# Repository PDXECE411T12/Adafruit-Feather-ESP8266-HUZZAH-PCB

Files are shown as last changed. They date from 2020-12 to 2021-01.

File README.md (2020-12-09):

# Modified for:
## ECE 411 Team 12 
### RFID Smart Lock

#### Fall 2020
#### Authors: Miles Breslin, Miguel Higgins Moy, John Sharpe, Noah Page

## Adafruit Feather HUZZAH with ESP8266 - Loose Headers PCB

<a href="http://www.adafruit.com/products/2821"><br/>
Click here to purchase one from the Adafruit shop</a>

PCB files for the Adafruit Feather HUZZAH with ESP8266 - Loose Headers. Format is EagleCAD schematic and board layout
* https://www.adafruit.com/product/2821

### Description

Feather is the new development board from Adafruit, and like its namesake it is thin, light, and lets you fly! We designed Feather to be a new standard for portable microcontroller cores.

This is the **Adafruit Feather HUZZAH ESP8266** - our take on an 'all-in-one' ESP8266 WiFi development board with built in USB and battery charging. Its an ESP8266 WiFi module with all the extras you need, ready to rock! [We have other boards in the Feather family, check'em out here.](https://www.adafruit.com/feather)

At the Feather HUZZAH's heart is an ESP8266 WiFi microcontroller clocked at 80 MHz and at 3.3V logic. This microcontroller contains a Tensilica chip core as well as a full WiFi stack. You can program the microcontroller using the Arduino IDE for an easy-to-run Internet of Things core. We wired up a high-quality SiLabs CP2104 USB-Serial chip that can upload code at a blistering 921600 baud for fast development time. It also has auto-reset so no noodling with pins and reset button pressings. The CP2104 has better driver support than the CH340 and can do very high speeds without stability issues.

To make it easy to use for portable projects, we added a connector for any of our 3.7V Lithium polymer batteries and built in battery charging. You don't need a battery, it will run just fine straight from the micro USB connector. But, if you do have a battery, you can take it on the go, then plug in the USB to recharge. The Feather will automatically switch over to USB power when its available.

**Here's some handy specs!**

 * Measures 2.0" x 0.9" x 0.28" (51mm x 23mm x 8mm) without headers soldered in
 * Light as a (large?) feather - 9.7 grams
 * ESP8266 @ 80MHz with 3.3V logic/power
 * 4MB of FLASH (32 MBit)
 * Built in WiFi 802.11 b/g/n
 * 3.3V regulator with 500mA peak current output
 * CP2104 USB-Serial converter onboard with 921600 max baudrate for speedy uploading
 * Auto-reset support for getting into bootload mode before firmware upload
 * 9 x GPIO pins - can also be used as I2C and SPI
 * 1 x analog inputs 1.0V max
 * Built in 100mA LiPoly charger with charging status indicator LED, can also cut a trace to disable the charger
 * Pin #0 red LED for general purpose blinking. Pin #2 blue LED for bootloading debug & general purpose blinking
 * Power/enable pin
 * 4 mounting holes
 * Reset button
Comes fully assembled and tested, with a USB interface that lets you quickly use it with the Arduino IDE or NodeMCU Lua (it comes preprogrammed with the Lua interpreter). We also toss in some headers so you can solder it in and plug into a solderless breadboard. **Lipoly battery and USB cable not included** (but we do have lots of options in the shop if you'd like!)

[Check out our tutorial for all sorts of details, including schematics, files, IDE instructions, power management and more!](https://learn.adafruit.com/adafruit-feather-huzzah-esp8266)

### License

Adafruit invests time and resources providing this open source design, please support Adafruit and open-source hardware by purchasing products from [Adafruit](https://www.adafruit.com)!

Designed by Limor Fried/Ladyada for Adafruit Industries.

Creative Commons Attribution/Share-Alike, all text above must be included in any redistribution. See license.txt for additional details.

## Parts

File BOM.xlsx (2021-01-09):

Bill Of Materials for: Team 12 RFID Door Lock
Last modified: 1/8/21
PCB version: F
BOM revision: 5 |  | P/NP | Place/Not Place (components marked NP are not stuffed on the board)
 |  |  |  |  |  |  |  |  |  |  |  |  | Combined Info for Bag Labels
Cnt | Part References | P/NP | Mfg | Value | Package | Mfg PN | Description | Dist | Dist Part Number | Link | Cost Ea. | Cost Total
1 | - | NP | OshPark | - | - | - | OshPark PCB | OshPark | - | - | $6.92 | $6.92 | QTY | REF | VALUE | PART#
1 | X1 | P | Espressif Systems | - | - | ESP-12E | Microcontroller | Digikey | 1528-1438-ND | https://www.digikey.com/en/products/detail/adafruit-industries-llc/2491/5761206 | $6.95 | $6.95
1 | M1 | NP | Tower Pro | - | - | MG90S | Micro servo | Smart Prototyping |  | https://www.smart-prototyping.com/MG90S-9g-metal-gear-digital-servo.html | $4.99 | $4.99 | 1 | X1 | - | 1528-1438-ND
1 | J1 | NP | NXP | - | - | MFRC522 | RFID Sensor | Amazon |  | https://www.amazon.com/MFRC-522-Reader-Inductive-Module-13-56MHz/dp/B07TYSF18Q | $1.99 | $1.99 | 1 | M1 | -
1 | X4 | P | Molex | 1050170001 | MOLEX_1050170001 | 1050170001 | USB Micro port | Digikey | WM1399CT-ND‎ | https://www.digikey.com/en/products/detail/molex,-llc/1050170001/2350885 | $0.69 | $0.69 | 1 | J1 | -
1 | U1G$1 | P | Silicon Labs | CP2104 | QFN24_4MM_SMSC | CP2104-F03-GM | USB to UART Bridge Controller | Digikey | 336-4146-1-ND | https://www.digikey.com/en/products/detail/silicon-labs/CP2104-F03-GMR/4069045 | $1.65 | $1.65 | 1 | X4 | 1050170001 | WM1399CT-ND‎
1 | Q3 | P | Alpha & Omega Semiconductor Inc. | AO3403 | SOT23-R | AO3403 | SOT-23 P-Channel MOSFET | Digikey | 785-1003-1-ND | https://www.digikey.com/en/products/detail/alpha-omega-semiconductor-inc/AO3403/1855775 | $0.28 | $0.28 | 1 | U1G$1 | CP2104 | 336-4146-1-ND
1 | AP2112-3.3 | P | MicroChip Technology | AP2112-3.3 | SOT25 | AP2112K-3.3TRG1 | Voltage Regulator | Digikey | AP2112K-3.3TRG1DICT-ND | https://www.digikey.com/en/products/detail/diodes-incorporated/AP2112K-3-3TRG1/4470746 | $0.36 | $0.36 | 1 | Q3 | AO3403 | 785-1003-1-ND
2 | JP2, JP3 | NP | Samtec Inc. | - | - | SSM-102-L-SV-BE | 1x2 Female Pin Header | Digikey |  | https://www.digikey.com/en/products/detail/samtec-inc/SSM-102-L-SV-BE/7859716 | $0.93 | $1.86 | 1 | AP2112-3.3 | AP2112-3.3 | AP2112K-3.3TRG1DICT-ND
1 | JP4 | NP | Samtec Inc. | - | - | SSM-116-L-SV-BE | 1x16 Female Pin Header | Digikey |  | https://www.digikey.com/en/products/detail/samtec-inc/SSM-116-L-SV-BE/6693187 | $2.95 | $2.95 | 2 | JP2, JP3 | -
1 | JP5 | NP | Samtec Inc. | - | - | SSM-112-L-SV-BE | 1x12 Female Header | Digikey |  | https://www.digikey.com/en/products/detail/samtec-inc/SSM-112-L-SV-BE/7860545 | $2.38 | $2.38 | 1 | JP4 | -
1 | R7 | P | Vishay Dale | 100k | 0603-MINI | CRCW0603100KFKEAHP‎ | 100kΩ Resistor | Digikey | 541-100KSCT-ND | https://www.digikey.com/en/products/detail/CRCW0603100KFKEAHP/541-100KSCT-ND/2222790?itemSeq=345258140 | $0.05 | $0.05 | 1 | JP5 | -
6 | R1, R3, R5, R6, R9, R10, R11 | P | Vishay Dale | 10k | 0603-MINI | CRCW060310K0FKEAHP‎ | 10kΩ Resistor | Digikey | 541-10.0KSCT-ND | https://www.digikey.com/en/products/detail/CRCW060310K0FKEAHP/541-10.0KSCT-ND/2222780?itemSeq=345258137 | $0.05 | $0.30 | 1 | R7 | 100k | 541-100KSCT-ND
1 | R2 | P | Vishay Dale | 1k | 0603-MINI | CRCW06031K00FKEAHP‎ | 1kΩ Resistor | Digikey | 541-1.00KSCT-ND | https://www.digikey.com/en/products/detail/CRCW06031K00FKEAHP/541-1.00KSCT-ND/2222766?itemSeq=345258145 | $0.05 | $0.05 | 6 | R1, R3, R5, R6, R9, R10, R11 | 10k | 541-10.0KSCT-ND
2 | R4, R8 | P | Vishay Dale | 4.7k | 0603-MINI | RCS06034K70FKEA‎ | 4.7kΩ Resistor | Digikey | 541-2792-1-ND | https://www.digikey.com/en/products/detail/RCS06034K70FKEA/541-2792-1-ND/5867085?itemSeq=345258142 | $0.04 | $0.08 | 1 | R2 | 1k | 541-1.00KSCT-ND
3 | C1, C2, C3 | P | Samsung EM | 10u | 0603-MINI | CL10X106MO8NRNC | 10µF Ceramic Capacitor | Digikey | 1276-6769-1-ND | https://www.digikey.com/en/products/detail/CL10X106MO8NRNC/1276-6769-1-ND/5961628?itemSeq=345262593 | $0.11 | $0.33 | 2 | R4, R8 | 4.7k | 541-2792-1-ND
1 | C4, | P | Samsung EM | 1u | 0603-MINI | CL10A105KO8NNNC | .1µF Ceramic Capacitor | Digikey | 1276-1034-1-ND | https://www.digikey.com/en/products/detail/CL10A105KO8NNNC/1276-1034-1-ND/3889120?itemSeq=345262622 | $0.02 | $0.02 | 3 | C1, C2, C3 | 10u | 1276-6769-1-ND
1 | C5 | P | Samsung EM | 100n | 0603-MINI | CL10B104KO8NNNC | 1µF Ceramic Capacitor | Digikey | 1276-1005-2-ND | https://www.digikey.com/en/products/detail/samsung-electro-mechanics/CL10B104KO8NNNC/3889091 | $0.01 | $0.01 | 1 | C4, | 1u | 1276-1034-1-ND
2 | T1, T2 | P | ON Semiconductor | 600mA/40V | SOT23-3 (Version 1) | MMBT2222ALT1G | NPN BJT | Digikey | MMBT2222ALT1GOSCT-ND | https://www.digikey.com/en/products/detail/MMBT2222ALT1G/MMBT2222ALT1GOSCT-ND/1139806?itemSeq=345263075 | $0.12 | $0.24 | 1 | C5 | 100n | 1276-1005-2-ND
1 | D4 | P | ON Semiconductor | 1A/40V | SOD-123 | MBR140SFT1G‎ | SOD-123 Schottky diode | Digikey | MBR140SFT1G | https://www.digikey.com/en/products/detail/on-semiconductor/MBR140SFT1G/918583 | $0.29 | $0.29 | 2 | T1, T2 | 600mA/40V | MMBT2222ALT1GOSCT-ND
1 | D2 | P | Kingbright | RED | CHIPLED_0603 | APT1608SURCK | 0603 Red LED | Digikey | 754-1123-1-ND | https://www.digikey.com/en/products/detail/kingbright/APT1608SURCK/1747522 | $0.21 | $0.21 | 1 | D4 | 1A/40V | MBR140SFT1G
1 | SW1 | P | Omron Electronics Inc-EMC Div | BB3S-1000 |  | BB3S-1000 | Tactile Switch | Digikey | SW415-ND | https://www.digikey.com/en/products/detail/omron-electronics-inc-emc-div/B3S-1000/20686 | $0.63 | $0.63 | 1 | D2 | RED | 754-1123-1-ND
3 | - | NP | Eneloop | AA - 1200mah | - | BK-3MCCA16FA | AA Batteries | Amazon | B00JHKSN4O | https://www.amazon.com/Panasonic-BK-3MCCA16FA-eneloop-Pre-Charged-Rechargeable/dp/B00JHKSN4O/ | $2.59 | $7.77 | 1 | SW1 | BB3S-1000 | SW415-ND
 |  |  |  |  |  |  |  |  |  |  | SUBTOTAL: | $41.00
Physical Items
1 | - | - | Miguel (3D printed) | - | PLA+ | - | Inner Door Mount | - |  |  | $0.26 | $0.26
1 | - | - | Miguel (3D printed) | - | PLA+ | - | Lock Plate Long | - |  |  | $0.32 | $0.32
1 | - | - | Miguel (3D printed) | - | PLA+ | - | Lock Cover | - |  |  | $0.32 | $0.32
1 | - | - | Miguel (3D printed) | - | PLA+ | - | Frame | - |  |  | $1.25 | $1.25
1 | - | - | Miguel (3D printed) | - | PLA+ | - | Battery PCB Frame | - |  |  | $1.22 | $1.22
1 | - | - | Miguel (3D printed) | - | PLA+ | - | Battery Cover | - |  |  | $0.21 | $0.21
1 | - | - | Miguel (3D printed) | - | PLA+ | - | Battery | - |  |  | $0.90 | $0.90
1 | - | - | Miguel (3D printed) | - | PLA+ | - | Cover | - |  |  | $0.76 | $0.76
1 | - | - | Miguel (3D printed) | - | PLA+ | - | Override | - |  |  | $0.28 | $0.28
12 | - | - | - | M3 Threaded Heatset Inserts | - | - | - | Amazon |  | https://www.amazon.com/gp/product/B087NBYF65 | $0.11 | $1.27
8 |  |  |  | M3x6 | Flat Head Screw |  |  | Amazon |  | https://www.amazon.com/gp/product/B07DDFR9Y3 | $0.09 | $0.72
4 |  |  |  | M3x8 | Flat Head Screw |  |  | Amazon |  | https://www.amazon.com/gp/product/B07DDFR9Y3 | $0.09 | $0.36
4 |  |  |  | M3x30 | Flat Head Screw |  |  | Amazon |  | https://www.amazon.com/gp/product/B07DDFR9Y3 | $0.09 | $0.36
 |  |  |  |  |  |  |  |  |  |  | SUBTOTAL: | $8.23
 |  |  |  |  |  |  |  |  |  |  | TOTAL COST | $49.23
VERSION INFO
Rev | Date | Notes
1.0r0 | 2020-11-11 | Initial BOM. Imported from Eagle and John's google sheet
1.0r1 | 2020-11-17 | Verifying component parts and footprints to match distributor sizes. Replaced Eagle button with button spec'd here.
1.0r3 | 2020-12-01 | Added 100nF Capacitor missing
1.0r4 | 2020-12-08 | Final Revision including Physical items and batteries
1.0r5 | 2021-01-07 | Added R11 for the pullup for the push to exit button
 | Total Run Costs | ~ $ 304.99

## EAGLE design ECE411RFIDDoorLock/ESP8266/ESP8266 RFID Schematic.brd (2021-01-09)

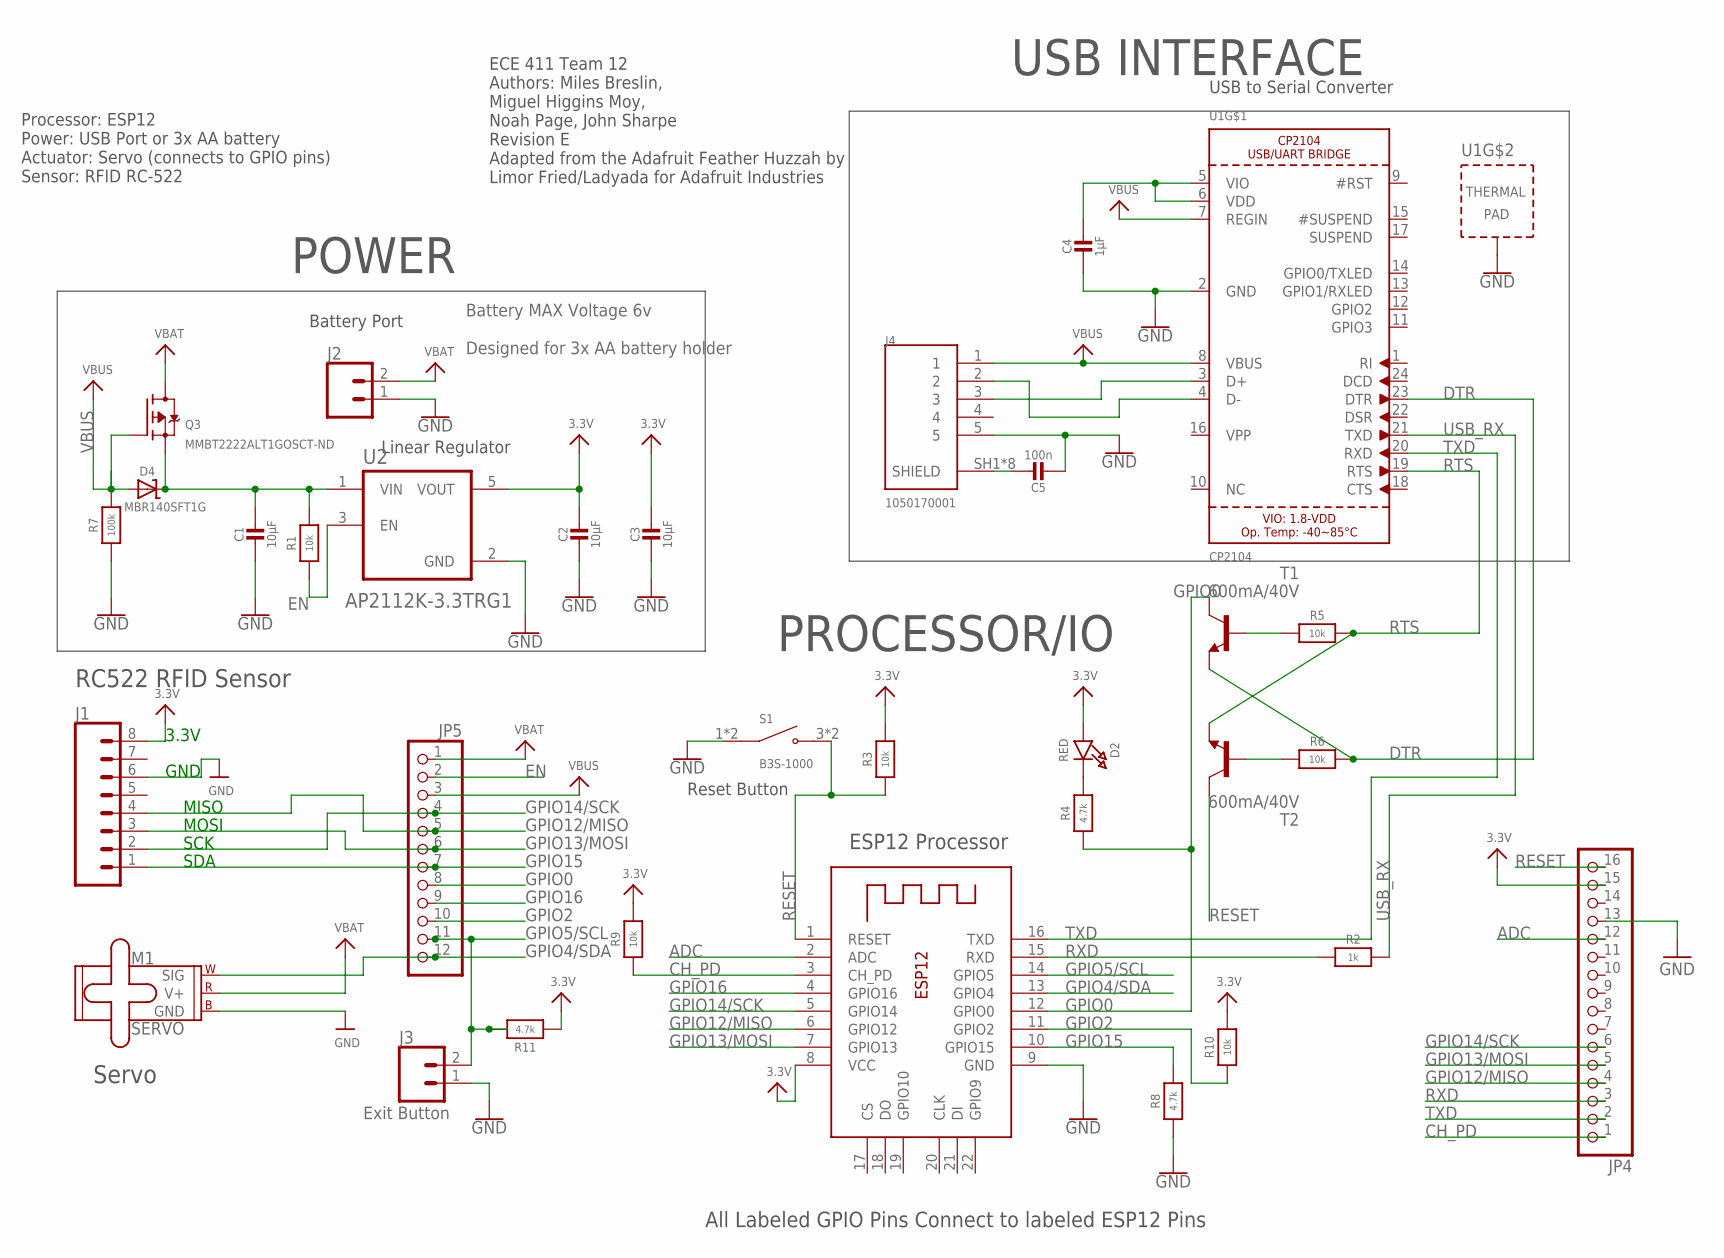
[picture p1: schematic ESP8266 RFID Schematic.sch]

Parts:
C1, C2, C3: 10µF; 0603-MINI
C4: 1µF; 0603-MINI
C5: 100n; 0603-MINI
D2: RED; CHIPLED_0603
D4: MBR140SFT1G; SOD-123
J1: CONN_08"; 1X08
J2, J3: CONN_02; 1X02
J4: 1050170001; MOLEX_1050170001
JP4: HEADER-1X16ROUND; 1X16_ROUND
JP5: HEADER-1X12; 1X12_ROUND
M1: SERVO; 1X03
Q3: MMBT2222ALT1GOSCT-ND; SOT23-R
R1, R3, R5, R6, R9, R10: 10k; 0603-MINI
R2: 1k; 0603-MINI
R4, R8, R11: 4.7k; 0603-MINI
R7: 100k; 0603-MINI
S1: B3S-1000; SW_B3S-1000
T1, T2: 600mA/40V; SOT23-3
U1: CP2104; QFN24_4MM_SMSC
U2: AP2112K-3.3TRG1; SOT95P285X140-5N
X1: ESP-12E

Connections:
3.3V: C2.1, C3.1, D2.A, J1.8, JP4.15, R3.2, R9.2, R10.2, R11.1, U2.5 (VOUT), X1.8 (VCC)
ADC: JP4.12, X1.2 (ADC)
CH_PD: JP4.1, R9.1, X1.3 (CH_PD)
DTR: R6.2, T1.2 (E), U1.23 (DTR)
EN: JP5.2, R1.1, U2.3 (EN)
GND: C1.2, C2.2, C3.2, C4.2, C5.2, J1.6, J2.1, J3.1, J4.5, JP4.13, M1.3 (GND), R7.1, R8.1, S1.1 (COM), S1.2 (COM), U1.2 (GND), U1.THERM (TP), U2.2 (GND), X1.9 (GND)
GPIO0: JP5.8, R4.1, T1.3 (C), X1.12 (GPIO0)
GPIO2: JP5.10, R10.1, X1.11 (GPIO2)
GPIO4/SDA: JP5.12, M1.1 (SIG), X1.13 (GPIO4)
GPIO5/SCL: J3.2, JP5.11, R11.2, X1.14 (GPIO5)
GPIO12/MISO: J1.4, JP4.4, JP5.5, X1.6 (GPIO12)
GPIO13/MOSI: J1.3, JP4.5, JP5.6, X1.7 (GPIO13)
GPIO14/SCK: J1.2, JP4.6, JP5.4, X1.5 (GPIO14)
GPIO15: J1.1, JP5.7, R8.2, X1.10 (GPIO15)
GPIO16: JP5.9, X1.4 (GPIO16)
unnamed: C5.1, J4.SH1 (SHIELD), J4.SH2 (SHIELD), J4.SH3 (SHIELD), J4.SH4 (SHIELD), J4.SH5 (SHIELD), J4.SH6 (SHIELD), J4.SH7 (SHIELD), J4.SH8 (SHIELD)
unnamed: J4.3, U1.3 (D+)
unnamed: J4.2, U1.4 (D-)
unnamed: D2.C, R4.2
unnamed: R5.1, T1.1 (B)
unnamed: R6.1, T2.1 (B)
unnamed: C1.1, D4.C, Q3.2 (S), R1.2, U2.1 (VIN)
unnamed: C4.1, U1.5 (VIO), U1.6 (VDD)
RESET: JP4.16, R3.1, S1.3 (NO), S1.4 (NO), T2.3 (C), X1.1 (RESET)
RTS: R5.2, T2.2 (E), U1.19 (RTS)
RXD: JP4.3, R2.1, X1.15 (RXD)
TXD: JP4.2, U1.20 (RXD), X1.16 (TXD)
USB_RX: R2.2, U1.21 (TXD)
VBAT: J2.2, JP5.1, M1.2 (V+), Q3.3 (D)
VBUS: D4.A, J4.1, JP5.3, Q3.1 (G), R7.2, U1.7 (REGIN), U1.8 (VBUS)

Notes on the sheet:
All Labeled GPIO Pins Connect to labeled ESP12 Pins
ESP12 Processor
Reset Button
USB to Serial Converter
Processor: ESP12 Power: USB Port or 3x AA battery Actuator: Servo (connects to GPIO pins) Sensor: RFID RC-522
POWER
USB INTERFACE
PROCESSOR/IO
SDA
SCK
MOSI
MISO
GND
3.3V
RC522 RFID Sensor
Servo
Linear Regulator
Battery Port
ECE 411 Team 12 Authors: Miles Breslin, Miguel Higgins Moy, Noah Page, John Sharpe Revision E Adapted from the Adafruit Feather Huzzah by Limor Fried/Ladyada for Adafruit Industries
Battery MAX Voltage 6v Designed for 3x AA battery holder
Exit Button

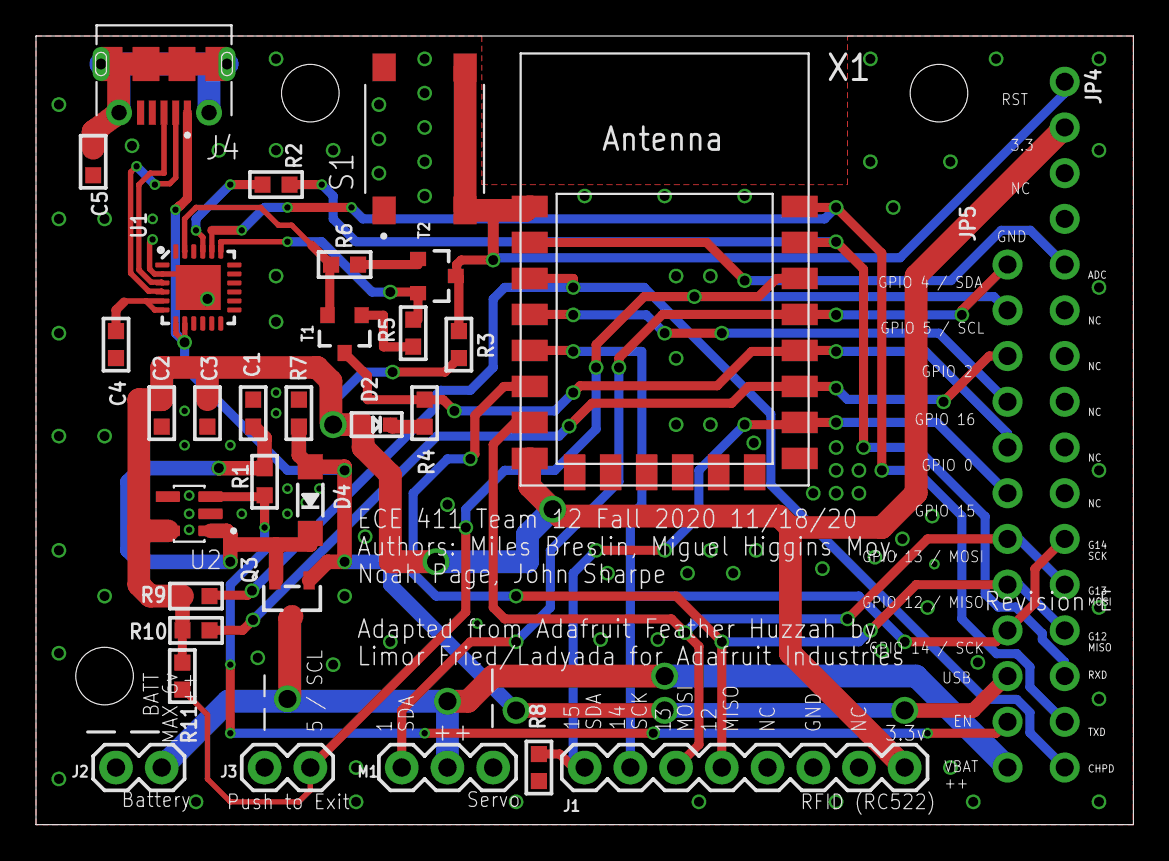
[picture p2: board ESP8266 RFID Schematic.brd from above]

Board: 2 copper layers, 61.0 x 43.8 mm, 32 parts (0 on the bottom side), 30 nets.

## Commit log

2020-11-08 Moved project Eagle files from main repo
    [Adafruit ESP8266 Feather rev E.brd, Adafruit ESP8266 Feather rev E.sch, Adafruit ESP8266 Feather.brd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]
2020-11-09 Update ESP8266 RFID Schematic.sch
    [ESP8266 RFID Schematic.sch]
2020-11-09 Update ESP8266 RFID Schematic.brd
    Added servo, RFID sensor, LIPO power port, and better labeling to schematic, did not work on board layout
    [ESP8266 RFID Schematic.brd]
2020-11-09 First pass at PCB layout
    [ESP8266 RFID Schematic.brd, ESP8266 RFID Schematic.sch]
2020-11-09 Traces Routed
    [ESP8266 RFID Schematic.brd]
2020-11-11 Added some missing component values
    [ESP8266 RFID Schematic.brd, ESP8266 RFID Schematic.sch]
2020-11-11 Added and routed resistors R8 - R10 that were missing from original schematic
    [ESP8266 RFID Schematic.brd]
2020-11-14 cleaned up some of the errors. Need to route 3.3V
    [ESP8266 RFID Schematic.brd, ESP8266 RFID Schematic.sch]
2020-11-14 Two ground planes, clean up, and power routing
    [ESP8266 RFID Schematic.brd, ESP8266 RFID Schematic.sch]
2020-11-14 added more ground stitching, iso on top pour, info layer on schematic
    [ESP8266 RFID Schematic.brd, ESP8266 RFID Schematic.sch]
2020-11-14 routed EN
    [ESP8266 RFID Schematic.brd, ESP8266 RFID Schematic.sch]
2020-11-15 Some VIA work and clean up
    [ESP8266 RFID Schematic.brd, ESP8266 RFID Schematic.sch]
2020-11-16 Design review feedback changed, USB replaced add new library
    [ESP8266 RFID Schematic.brd, ESP8266 RFID Schematic.sch]
2020-11-16 PCB Clean Up from Design Review
    [ESP8266 RFID Schematic.brd, ESP8266 RFID Schematic.sch]
2020-11-18 Final PCB Draft, some component modifications, please take a look.
    [ESP8266 RFID Schematic.brd, ESP8266 RFID Schematic.sch]
2020-11-18 Final PCB draft
    [ESP8266 RFID Schematic.brd, ESP8266 RFID Schematic.sch]
2020-11-21 Added pull up resistor to push to exit
    [ESP8266 RFID Schematic.brd, ESP8266 RFID Schematic.sch]
2020-12-09 Readme update and organizing
    [Adafruit ESP8266 Feather rev G.brd, Adafruit ESP8266 Feather rev G.sch, ESP8266 RFID Schematic.brd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]
2021-01-09 Fixes and updates
    [ESP8266 RFID Schematic.brd, ESP8266 RFID Schematic.sch]
2021-01-09 Remove Adafruit Board as reference and added BOM
    [Adafruit ESP8266 Feather rev G.brd, Adafruit ESP8266 Feather rev G.sch, BOM.xlsx]

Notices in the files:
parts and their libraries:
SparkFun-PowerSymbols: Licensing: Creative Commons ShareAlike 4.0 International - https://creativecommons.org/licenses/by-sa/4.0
